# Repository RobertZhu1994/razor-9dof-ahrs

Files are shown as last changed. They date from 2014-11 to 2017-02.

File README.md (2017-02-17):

Razor AHRS v1.4.2
---

This is a "fab-able" version of the <a href="https://www.sparkfun.com/products/retired/10736">Sparkfun 9DOF IMU board</a>, modified so that it can be made with a desktop CNC router.

Full documentation on <a href="https://www.instructables.com/id/9-Degrees-of-Freedom-IMU/">Instructables</a>.

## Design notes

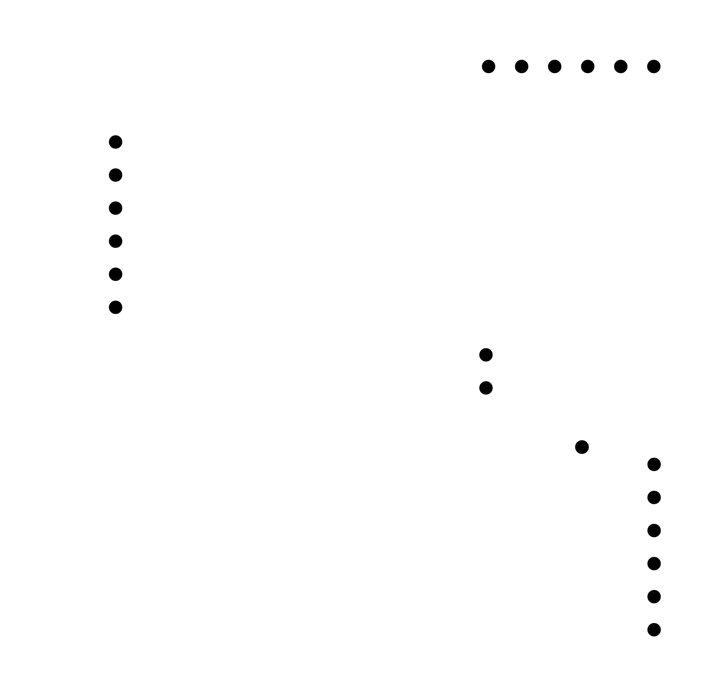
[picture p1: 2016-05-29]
PCB/9DofEagle-Holes.png

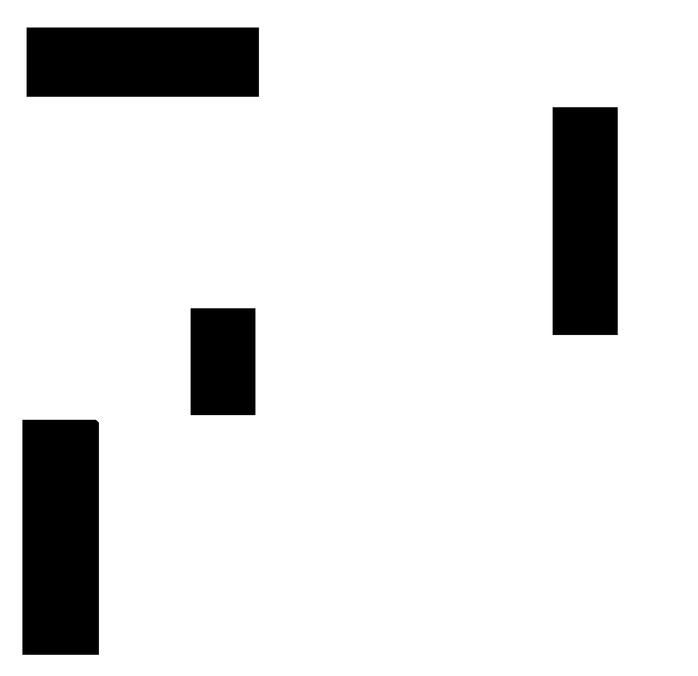
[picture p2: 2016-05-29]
PCB/9DofEagle-Back.png

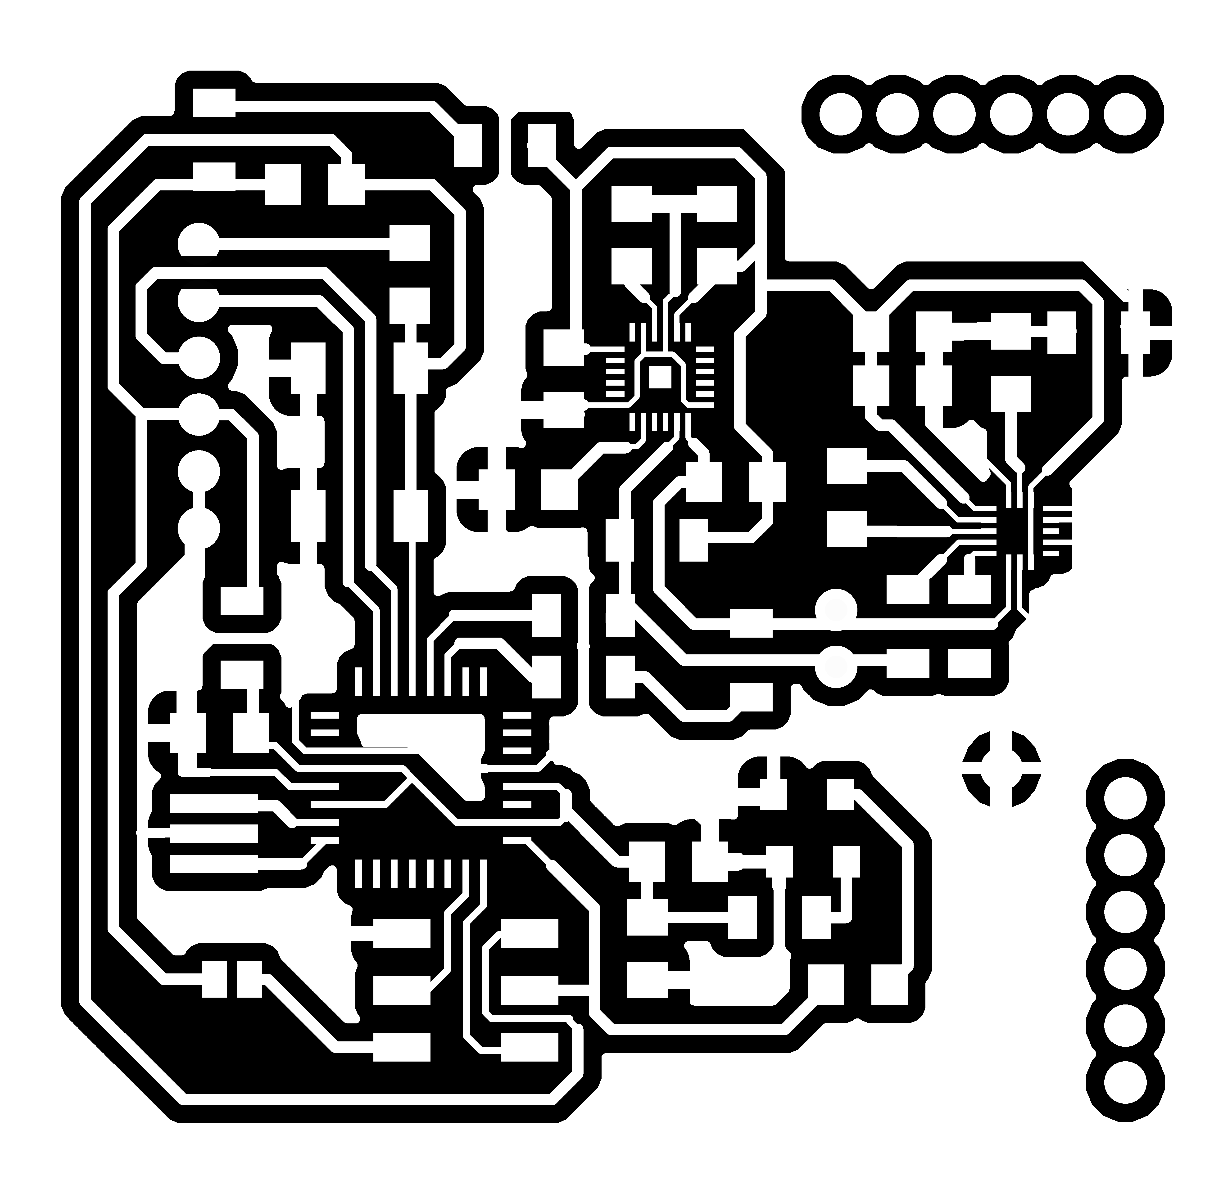
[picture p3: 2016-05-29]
PCB/9DofEagle-Traces.png

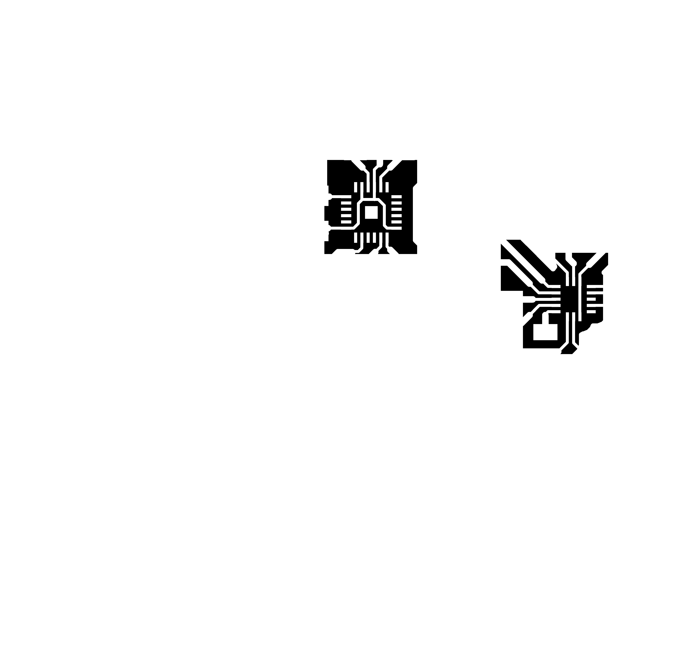
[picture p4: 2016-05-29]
PCB/9DofEagle-Detail.png

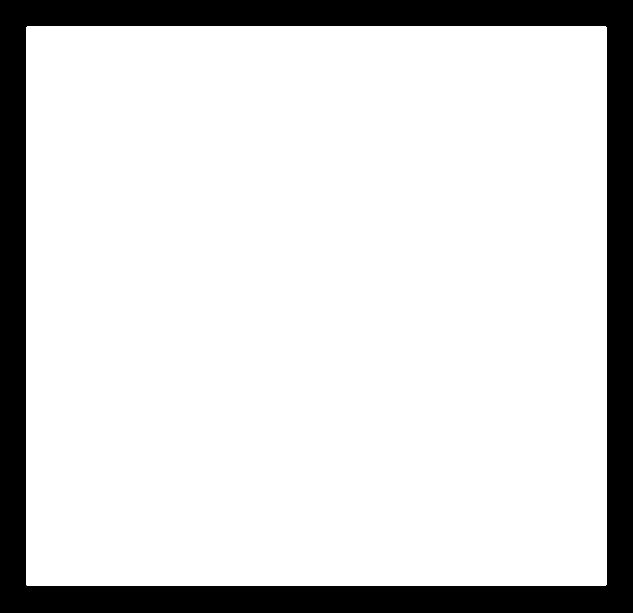
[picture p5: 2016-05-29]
PCB/9DofEagle-Outline.png

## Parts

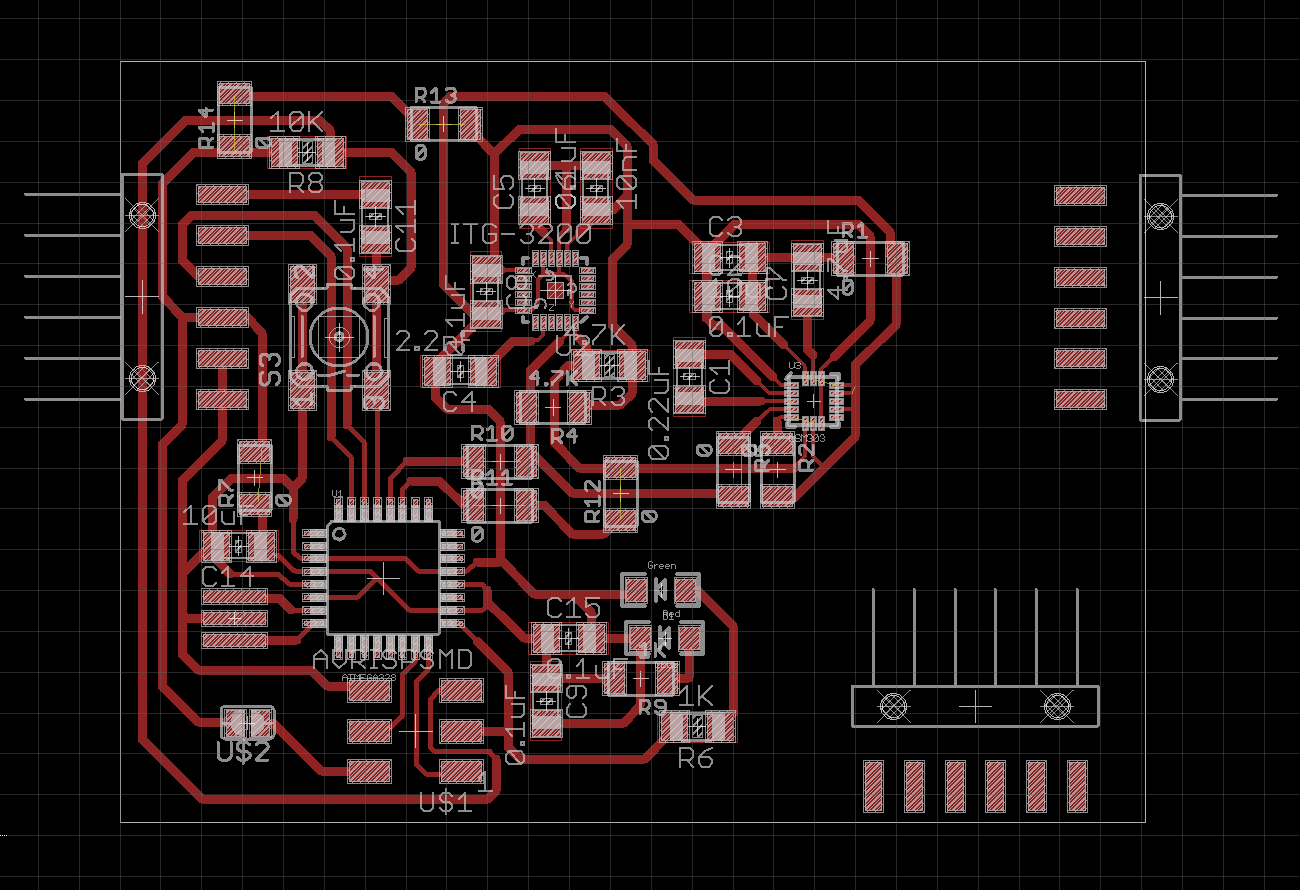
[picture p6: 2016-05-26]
PCB/Components.png

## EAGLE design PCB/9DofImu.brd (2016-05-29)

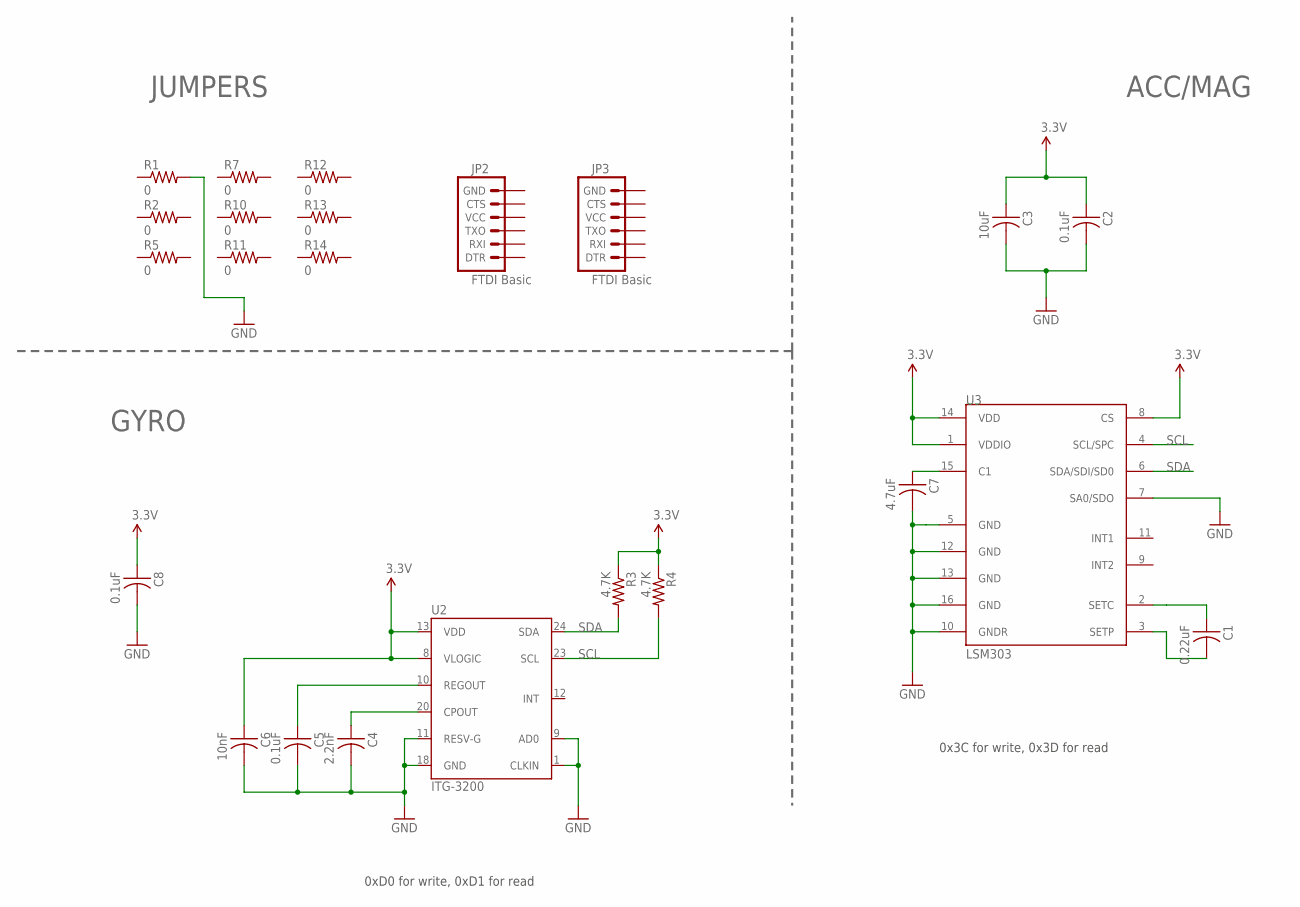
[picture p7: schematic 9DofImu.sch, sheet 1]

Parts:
C1: 0.22uF; C1206
C2, C5, C8: 0.1uF; C1206
C3: 10uF; C1206
C4: 2.2nF; C1206
C6: 10nF; C1206
C7: 4.7uF; C1206
JP2, JP3: FTDI Basic; 1X06-KIT
R1, R2, R5, R7, R10, R11, R12, R13, R14: 0; R1206FAB
R3: 4.7K; R1206
R4: 4.7K; R1206FAB
U2: ITG-3200; QFN-24
U3: LSM303; LGA16-3MM

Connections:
3.3V: C2.1, C3.1, C6.1, C8.1, R3.1, R4.1, U2.8 (VLOGIC), U2.13 (VDD), U3.1 (VDDIO), U3.8 (CS), U3.14 (VDD); also elsewhere on the board
GND: C2.2, C3.2, C4.2, C5.2, C6.2, C7.2, C8.2, R1.2, U2.1 (CLKIN), U2.9 (AD0), U2.11 (RESV-G), U2.18 (GND), U3.5 (GND), U3.7 (SA0/SDO), U3.10 (GNDR), U3.12 (GND), U3.13 (GND), U3.16 (GND); also elsewhere on the board
unnamed: C4.1, U2.20 (CPOUT)
unnamed: C5.1, U2.10 (REGOUT)
unnamed: C7.1, U3.15 (C1)
unnamed: C1.1, U3.2 (SETC)
unnamed: C1.2, U3.3 (SETP)
SCL: R4.2, U2.23 (SCL), U3.4 (SCL/SPC); also elsewhere on the board
SDA: R3.2, U2.24 (SDA), U3.6 (SDA/SDI/SD0); also elsewhere on the board

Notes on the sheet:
0xD0 for write, 0xD1 for read
0x3C for write, 0x3D for read
JUMPERS
ACC/MAG
GYRO

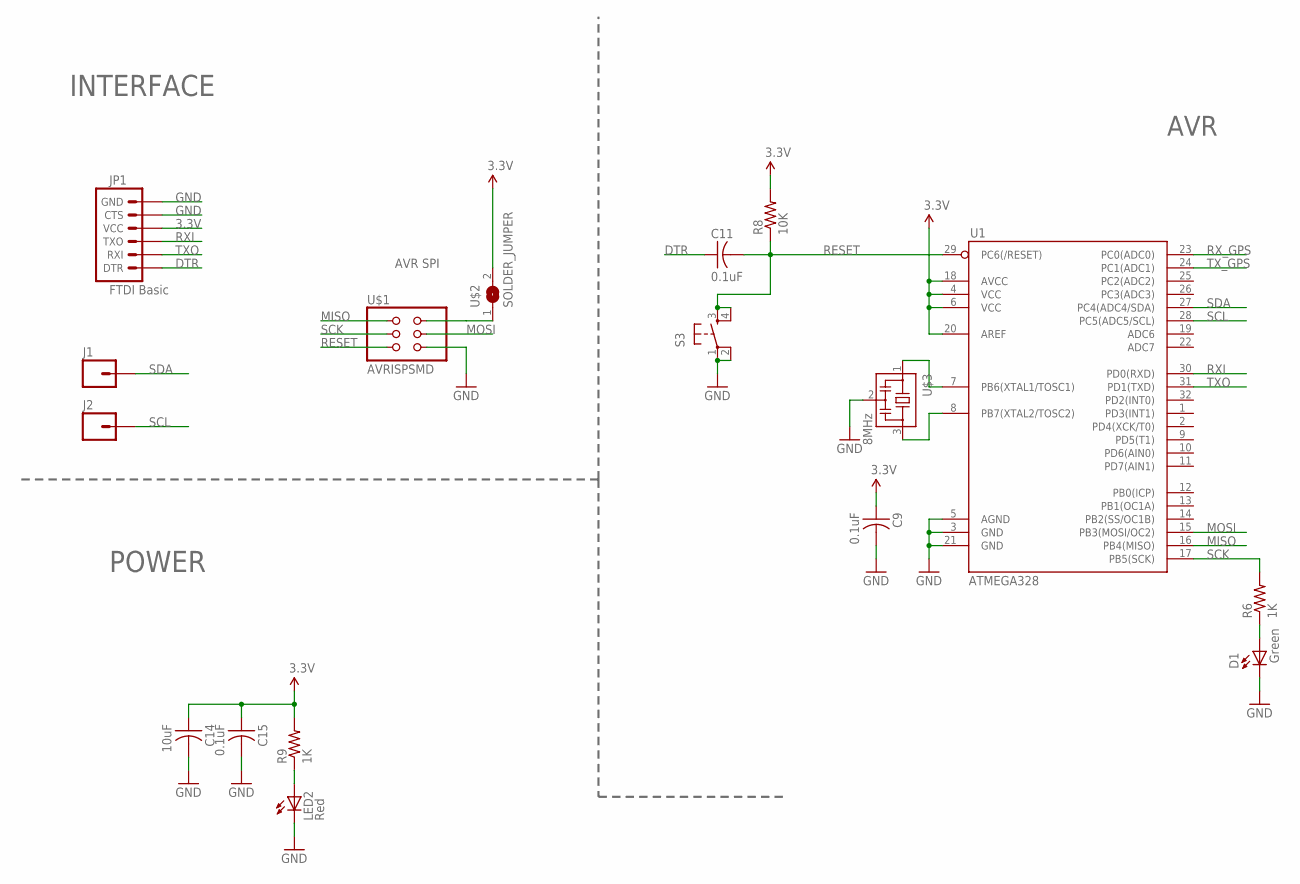
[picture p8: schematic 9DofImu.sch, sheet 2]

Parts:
C9, C11, C15: 0.1uF; C1206
C14: 10uF; C1206
D1: Green; LED-1206
J1, J2: M01PTH; 1X01
JP1: FTDI Basic; 1X06-KIT
LED2: Red; LED-1206
R6: 1K; R1206
R8: 10K; R1206
R9: 1K; R1206FAB
S3: 6MM_SWITCH6MM_SWITCH; 6MM_SWITCH
U1: ATMEGA328; TQFP32-08
U$1: AVRISPSMD; 2X03SMD
U$2: SOLDER_JUMPER; SJFAB
U$3: 8MHz; EFOBM

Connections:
3.3V: C9.1, C14.1, C15.1, JP1.4 (VCC), R8.2, R9.2, U1.4 (VCC), U1.6 (VCC), U1.18 (AVCC), U1.20 (AREF), U$2.2; also elsewhere on the board
DTR: C11.1, JP1.1 (DTR)
GND: C9.2, C14.2, C15.2, D1.C, JP1.5 (CTS), JP1.6 (GND), LED2.C, S3.1, S3.2 (P1), U1.3 (GND), U1.5 (AGND), U1.21 (GND), U$1.6 (GND), U$3.2; also elsewhere on the board
MISO: U1.16 (PB4(MISO)), U$1.1 (MISO)
MOSI: U1.15 (PB3(MOSI/OC2)), U$1.4 (MOSI)
unnamed: LED2.A, R9.1
unnamed: U$1.2 (VCC), U$2.1
unnamed: D1.A, R6.1
unnamed: U1.8 (PB7(XTAL2/TOSC2)), U$3.3
unnamed: U1.7 (PB6(XTAL1/TOSC1)), U$3.1
RESET: C11.2, R8.1, S3.3 (S), S3.4 (S1), U1.29 (PC6(/RESET)), U$1.5 (RST)
RXI: JP1.3 (TXO), U1.30 (PD0(RXD))
RX_GPS: U1.23 (PC0(ADC0))
SCK: R6.2, U1.17 (PB5(SCK)), U$1.3 (SCK)
SCL: J2.1, U1.28 (PC5(ADC5/SCL)); also elsewhere on the board
SDA: J1.1, U1.27 (PC4(ADC4/SDA)); also elsewhere on the board
TXO: JP1.2 (RXI), U1.31 (PD1(TXD))
TX_GPS: U1.24 (PC1(ADC1))

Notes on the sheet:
AVR
INTERFACE
POWER
AVR SPI

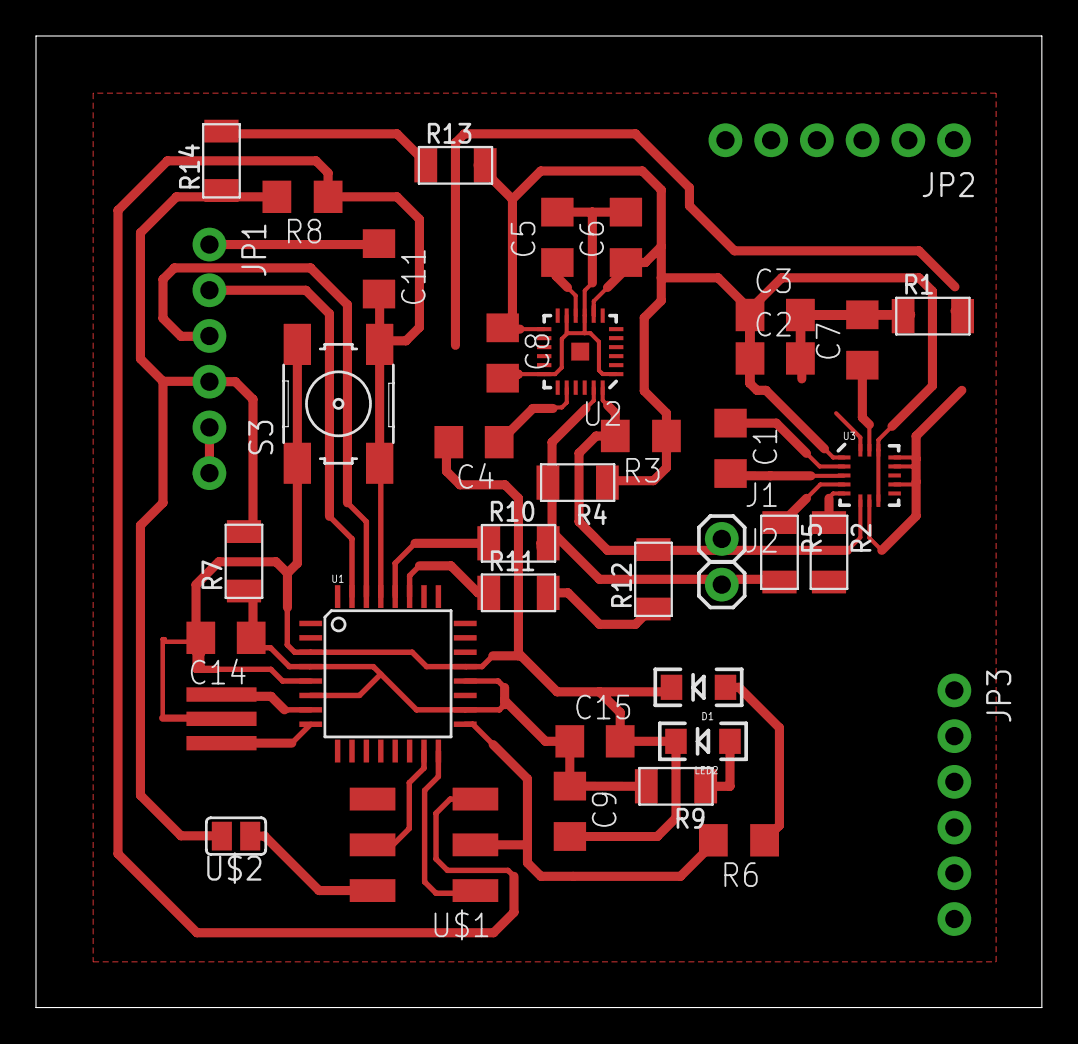
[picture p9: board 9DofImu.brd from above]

Board: 2 copper layers, 55.9 x 54.0 mm, 40 parts (0 on the bottom side), 21 nets.

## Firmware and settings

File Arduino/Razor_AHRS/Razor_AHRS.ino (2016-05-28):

/***************************************************************************************************************
* Razor AHRS Firmware v1.4.2 mod
* 9 Degree of Measurement Attitude and Heading Reference System
* for Sparkfun "9DOF Razor IMU" (SEN-10125 and SEN-10736)
* and "9DOF Sensor Stick" (SEN-10183, 10321 and SEN-10724)
*
* Released under GNU GPL (General Public License) v3.0
* Copyright (C) 2013 Peter Bartz [http://ptrbrtz.net]
* Copyright (C) 2011-2012 Quality & Usability Lab, Deutsche Telekom Laboratories, TU Berlin
*
* Infos, updates, bug reports, contributions and feedback:
*     https://github.com/ptrbrtz/razor-9dof-ahrs
*
*
* History:
*   * Original code (http://code.google.com/p/sf9domahrs/) by Doug Weibel and Jose Julio,
*     based on ArduIMU v1.5 by Jordi Munoz and William Premerlani, Jose Julio and Doug Weibel. Thank you!
*
*   * Updated code (http://groups.google.com/group/sf_9dof_ahrs_update) by David Malik (david.zsolt.malik@gmail.com)
*     for new Sparkfun 9DOF Razor hardware (SEN-10125).
*
*   * Updated and extended by Peter Bartz (peter-bartz@gmx.de):
*     * v1.3.0
*       * Cleaned up, streamlined and restructured most of the code to make it more comprehensible.
*       * Added sensor calibration (improves precision and responsiveness a lot!).
*       * Added binary yaw/pitch/roll output.#oc
*       * Added basic serial command interface to set output modes/calibrate sensors/synch stream/etc.
*       * Added support to synch automatically when using Rovering Networks Bluetooth modules (and compatible).
*       * Wrote new easier to use test program (using Processing).
*       * Added support for new version of "9DOF Razor IMU": SEN-10736.
*       --> The output of this code is not compatible with the older versions!
*       --> A Processing sketch to test the tracker is available.
*     * v1.3.1
*       * Initializing rotation matrix based on start-up sensor readings -> orientation OK right away.
*       * Adjusted gyro low-pass filter and output rate settings.
*     * v1.3.2
*       * Adapted code to work with new Arduino 1.0 (and older versions still).
*     * v1.3.3
*       * Improved synching.
*     * v1.4.0
*       * Added support for SparkFun "9DOF Sensor Stick" (versions SEN-10183, SEN-10321 and SEN-10724).
*     * v1.4.1
*       * Added output modes to read raw and/or calibrated sensor data in text or binary format.
*       * Added static magnetometer soft iron distortion compensation
*     * v1.4.2
*       * (No core firmware changes)
*
* TODOs:
*   * Allow optional use of EEPROM for storing and reading calibration values.
*   * Use self-test and temperature-compensation features of the sensors.
***************************************************************************************************************/

/*
  "9DOF Razor IMU" hardware versions: SEN-10125 and SEN-10736

  ATMega328@3.3V, 8MHz

  ADXL345  : Accelerometer
  HMC5843  : Magnetometer on SEN-10125
  HMC5883L : Magnetometer on SEN-10736
  ITG-3200 : Gyro

  Arduino IDE : Select board "Arduino Pro or Pro Mini (3.3v, 8Mhz) w/ATmega328"
*/

/*
  "9DOF Sensor Stick" hardware versions: SEN-10183, SEN-10321 and SEN-10724

  ADXL345  : Accelerometer
  HMC5843  : Magnetometer on SEN-10183 and SEN-10321
  HMC5883L : Magnetometer on SEN-10724
  ITG-3200 : Gyro
*/

/*
  Axis definition (differs from definition printed on the board!):
    X axis pointing forward (towards the short edge with the connector holes)
    Y axis pointing to the right
    and Z axis pointing down.
    
  Positive yaw   : clockwise
  Positive roll  : right wing down
  Positive pitch : nose up
  
  Transformation order: first yaw then pitch then roll.
*/

/*
  Serial commands that the firmware understands:
  
  "#o<params>" - Set OUTPUT mode and parameters. The available options are:
  
      // Streaming output
      "#o0" - DISABLE continuous streaming output. Also see #f below.
      "#o1" - ENABLE continuous streaming output.
      
      // Angles output
      "#ob" - Output angles in BINARY format (yaw/pitch/roll as binary float, so one output frame
              is 3x4 = 12 bytes long).
      "#ot" - Output angles in TEXT format (Output frames have form like "#YPR=-142.28,-5.38,33.52",
              followed by carriage return and line feed [\r\n]).
      
      // Sensor calibration
      "#oc" - Go to CALIBRATION output mode.
      "#on" - When in calibration mode, go on to calibrate NEXT sensor.
      
      // Sensor data output
      "#osct" - Output CALIBRATED SENSOR data of all 9 axes in TEXT format.
                One frame consist of three lines - one for each sensor: acc, mag, gyr.
      "#osrt" - Output RAW SENSOR data of all 9 axes in TEXT format.
                One frame consist of three lines - one for each sensor: acc, mag, gyr.
      "#osbt" - Output BOTH raw and calibrated SENSOR data of all 9 axes in TEXT format.
                One frame consist of six lines - like #osrt and #osct combined (first RAW, then CALIBRATED).
                NOTE: This is a lot of number-to-text conversion work for the little 8MHz chip on the Razor boards.
                In fact it's too much and an output frame rate of 50Hz can not be maintained. #osbb.
      "#oscb" - Output CALIBRATED SENSOR data of all 9 axes in BINARY format.
                One frame consist of three 3x3 float values = 36 bytes. Order is: acc x/y/z, mag x/y/z, gyr x/y/z.
      "#osrb" - Output RAW SENSOR data of all 9 axes in BINARY format.
                One frame consist of three 3x3 float values = 36 bytes. Order is: acc x/y/z, mag x/y/z, gyr x/y/z.
      "#osbb" - Output BOTH raw and calibrated SENSOR data of all 9 axes in BINARY format.
                One frame consist of 2x36 = 72 bytes - like #osrb and #oscb combined (first RAW, then CALIBRATED).
      
      // Error message output        
      "#oe0" - Disable ERROR message output.
      "#oe1" - Enable ERROR message output.
    
    
  "#f" - Request one output frame - useful when continuous output is disabled and updates are
         required in larger intervals only. Though #f only requests one reply, replies are still
         bound to the internal 20ms (50Hz) time raster. So worst case delay that #f can add is 19.99ms.
         
         
  "#s<xy>" - Request synch token - useful to find out where the frame boundaries are in a continuous
         binary stream or to see if tracker is present and answering. The tracker will send
         "#SYNCH<xy>\r\n" in response (so it's possible to read using a readLine() function).
         x and y are two mandatory but arbitrary bytes that can be used to find out which request
         the answer belongs to.
          
          
  ("#C" and "#D" - Reserved for communication with optional Bluetooth module.)
  
  Newline characters are not required. So you could send "#ob#o1#s", which
  would set binary output mode, enable continuous streaming output and request
  a synch token all at once.
  
  The status LED will be on if streaming output is enabled and off otherwise.
  
  Byte order of binary output is little-endian: least significant byte comes first.
*/



/*****************************************************************/
/*********** USER SETUP AREA! Set your options here! *************/
/*****************************************************************/

// HARDWARE OPTIONS
/*****************************************************************/
// Select your hardware here by uncommenting one line!
#define HW__VERSION_CODE 10125 // SparkFun "9DOF Razor IMU" version "SEN-10125" (HMC5843 magnetometer)
//#define HW__VERSION_CODE 10736 // SparkFun "9DOF Razor IMU" version "SEN-10736" (HMC5883L magnetometer)
//#define HW__VERSION_CODE 10183 // SparkFun "9DOF Sensor Stick" version "SEN-10183" (HMC5843 magnetometer)
//#define HW__VERSION_CODE 10321 // SparkFun "9DOF Sensor Stick" version "SEN-10321" (HMC5843 magnetometer)
//#define HW__VERSION_CODE 10724 // SparkFun "9DOF Sensor Stick" version "SEN-10724" (HMC5883L magnetometer)


// OUTPUT OPTIONS
/*****************************************************************/
// Set your serial port baud rate used to send out data here!
#define OUTPUT__BAUD_RATE 57600

// Sensor data output interval in milliseconds
// This may not work, if faster than 20ms (=50Hz)
// Code is tuned for 20ms, so better leave it like that
#define OUTPUT__DATA_INTERVAL 20  // in milliseconds

// Output mode definitions (do not change)
#define OUTPUT__MODE_CALIBRATE_SENSORS 0 // Outputs sensor min/max values as text for manual calibration
#define OUTPUT__MODE_ANGLES 1 // Outputs yaw/pitch/roll in degrees
#define OUTPUT__MODE_SENSORS_CALIB 2 // Outputs calibrated sensor values for all 9 axes
#define OUTPUT__MODE_SENSORS_RAW 3 // Outputs raw (uncalibrated) sensor values for all 9 axes
#define OUTPUT__MODE_SENSORS_BOTH 4 // Outputs calibrated AND raw sensor values for all 9 axes
// Output format definitions (do not change)
#define OUTPUT__FORMAT_TEXT 0 // Outputs data as text
#define OUTPUT__FORMAT_BINARY 1 // Outputs data as binary float

// Select your startup output mode and format here!
int output_mode = OUTPUT__MODE_ANGLES;
int output_format = OUTPUT__FORMAT_TEXT;

// Select if serial continuous streaming output is enabled per default on startup.
#define OUTPUT__STARTUP_STREAM_ON true  // true or false

// If set true, an error message will be output if we fail to read sensor data.
// Message format: "!ERR: reading <sensor>", followed by "\r\n".
boolean output_errors = false;  // true or false

// Bluetooth
// You can set this to true, if you have a Rovering Networks Bluetooth Module attached.
// The connect/disconnect message prefix of the module has to be set to "#".
// (Refer to manual, it can be set like this: SO,#)
// When using this, streaming output will only be enabled as long as we're connected. That way
// receiver and sender are synchronzed easily just by connecting/disconnecting.
// It is not necessary to set this! It just makes life easier when writing code for
// the receiving side. The Processing test sketch also works without setting this.
// NOTE: When using this, OUTPUT__STARTUP_STREAM_ON has no effect!
#define OUTPUT__HAS_RN_BLUETOOTH false  // true or false


// SENSOR CALIBRATION
/*****************************************************************/
// How to calibrate? Read the tutorial at http://dev.qu.tu-berlin.de/projects/sf-razor-9dof-ahrs
// Put MIN/MAX and OFFSET readings for your board here!
// Accelerometer
// "accel x,y,z (min/max) = X_MIN/X_MAX  Y_MIN/Y_MAX  Z_MIN/Z_MAX"
#define ACCEL_X_MIN ((float) -292)
#define ACCEL_X_MAX ((float) 267)
#define ACCEL_Y_MIN ((float) -280)
#define ACCEL_Y_MAX ((float) 267)
#define ACCEL_Z_MIN ((float) -289)
#define ACCEL_Z_MAX ((float) 262)

// Magnetometer (standard calibration mode)
// "magn x,y,z (min/max) = X_MIN/X_MAX  Y_MIN/Y_MAX  Z_MIN/Z_MAX"
#define MAGN_X_MIN ((float) -632)
#define MAGN_X_MAX ((float) 761)
#define MAGN_Y_MIN ((float) -621)
#define MAGN_Y_MAX ((float) 698)
#define MAGN_Z_MIN ((float) -780)
#define MAGN_Z_MAX ((float) 703)

// Magnetometer (extended calibration mode)
// Uncommend to use extended magnetometer calibration (compensates hard & soft iron errors)
//#define CALIBRATION__MAGN_USE_EXTENDED true
//const float magn_ellipsoid_center[3] = {0, 0, 0};
//const float magn_ellipsoid_transform[3][3] = {{0, 0, 0}, {0, 0, 0}, {0, 0, 0}};

// Gyroscope
// "gyro x,y,z (current/average) = .../OFFSET_X  .../OFFSET_Y  .../OFFSET_Z
#define GYRO_AVERAGE_OFFSET_X ((float) -24.75)
#define GYRO_AVERAGE_OFFSET_Y ((float) 75.10)
#define GYRO_AVERAGE_OFFSET_Z ((float) -7.98)

/*
// Calibration example:

// "accel x,y,z (min/max) = -277.00/264.00  -256.00/278.00  -299.00/235.00"
#define ACCEL_X_MIN ((float) -277)
#define ACCEL_X_MAX ((float) 264)
#define ACCEL_Y_MIN ((float) -256)
#define ACCEL_Y_MAX ((float) 278)
#define ACCEL_Z_MIN ((float) -299)
#define ACCEL_Z_MAX ((float) 235)

// "magn x,y,z (min/max) = -511.00/581.00  -516.00/568.00  -489.00/486.00"
//#define MAGN_X_MIN ((float) -511)
//#define MAGN_X_MAX ((float) 581)
//#define MAGN_Y_MIN ((float) -516)
//#define MAGN_Y_MAX ((float) 568)
//#define MAGN_Z_MIN ((float) -489)
//#define MAGN_Z_MAX ((float) 486)

// Extended magn
#define CALIBRATION__MAGN_USE_EXTENDED true
const float magn_ellipsoid_center[3] = {91.5, -13.5, -48.1};
const float magn_ellipsoid_transform[3][3] = {{0.902, -0.00354, 0.000636}, {-0.00354, 0.9, -0.00599}, {0.000636, -0.00599, 1}};

// Extended magn (with Sennheiser HD 485 headphones)
//#define CALIBRATION__MAGN_USE_EXTENDED true
//const float magn_ellipsoid_center[3] = {72.3360, 23.0954, 53.6261};
//const float magn_ellipsoid_transform[3][3] = {{0.879685, 0.000540833, -0.0106054}, {0.000540833, 0.891086, -0.0130338}, {-0.0106054, -0.0130338, 0.997494}};

//"gyro x,y,z (current/average) = -40.00/-42.05  98.00/96.20  -18.00/-18.36"
#define GYRO_AVERAGE_OFFSET_X ((float) -42.05)
#define GYRO_AVERAGE_OFFSET_Y ((float) 96.20)
#define GYRO_AVERAGE_OFFSET_Z ((float) -18.36)
*/


// DEBUG OPTIONS
/*****************************************************************/
// When set to true, gyro drift correction will not be applied
#define DEBUG__NO_DRIFT_CORRECTION false
// Print elapsed time after each I/O loop
#define DEBUG__PRINT_LOOP_TIME false


/*****************************************************************/
/****************** END OF USER SETUP AREA!  *********************/
/*****************************************************************/










// Check if hardware version code is defined
#ifndef HW__VERSION_CODE
  // Generate compile error
  #error YOU HAVE TO SELECT THE HARDWARE YOU ARE USING! See "HARDWARE OPTIONS" in "USER SETUP AREA" at top of Razor_AHRS.ino!
#endif

#include <Wire.h>

// Sensor calibration scale and offset values
#define ACCEL_X_OFFSET ((ACCEL_X_MIN + ACCEL_X_MAX) / 2.0f)
#define ACCEL_Y_OFFSET ((ACCEL_Y_MIN + ACCEL_Y_MAX) / 2.0f)
#define ACCEL_Z_OFFSET ((ACCEL_Z_MIN + ACCEL_Z_MAX) / 2.0f)
#define ACCEL_X_SCALE (GRAVITY / (ACCEL_X_MAX - ACCEL_X_OFFSET))
#define ACCEL_Y_SCALE (GRAVITY / (ACCEL_Y_MAX - ACCEL_Y_OFFSET))
#define ACCEL_Z_SCALE (GRAVITY / (ACCEL_Z_MAX - ACCEL_Z_OFFSET))

#define MAGN_X_OFFSET ((MAGN_X_MIN + MAGN_X_MAX) / 2.0f)
#define MAGN_Y_OFFSET ((MAGN_Y_MIN + MAGN_Y_MAX) / 2.0f)
#define MAGN_Z_OFFSET ((MAGN_Z_MIN + MAGN_Z_MAX) / 2.0f)
#define MAGN_X_SCALE (100.0f / (MAGN_X_MAX - MAGN_X_OFFSET))
#define MAGN_Y_SCALE (100.0f / (MAGN_Y_MAX - MAGN_Y_OFFSET))
#define MAGN_Z_SCALE (100.0f / (MAGN_Z_MAX - MAGN_Z_OFFSET))


// Gain for gyroscope (ITG-3200)
#define GYRO_GAIN 0.06957 // Same gain on all axes
#define GYRO_SCALED_RAD(x) (x * TO_RAD(GYRO_GAIN)) // Calculate the scaled gyro readings in radians per second

// DCM parameters
#define Kp_ROLLPITCH 0.02f
#define Ki_ROLLPITCH 0.00002f
#define Kp_YAW 1.2f
#define Ki_YAW 0.00002f

// Stuff
#define STATUS_LED_PIN 13  // Pin number of status LED
#define GRAVITY 256.0f // "1G reference" used for DCM filter and accelerometer calibration
#define TO_RAD(x) (x * 0.01745329252)  // *pi/180
#define TO_DEG(x) (x * 57.2957795131)  // *180/pi

// Sensor variables
float accel[3];  // Actually stores the NEGATED acceleration (equals gravity, if board not moving).
float accel_min[3];
float accel_max[3];

float magnetom[3];
float magnetom_min[3];
float magnetom_max[3];
float magnetom_tmp[3];

float gyro[3];
float gyro_average[3];
int gyro_num_samples = 0;

// DCM variables
float MAG_Heading;
float Accel_Vector[3]= {0, 0, 0}; // Store the acceleration in a vector
float Gyro_Vector[3]= {0, 0, 0}; // Store the gyros turn rate in a vector
float Omega_Vector[3]= {0, 0, 0}; // Corrected Gyro_Vector data
float Omega_P[3]= {0, 0, 0}; // Omega Proportional correction
float Omega_I[3]= {0, 0, 0}; // Omega Integrator
float Omega[3]= {0, 0, 0};
float errorRollPitch[3] = {0, 0, 0};
float errorYaw[3] = {0, 0, 0};
float DCM_Matrix[3][3] = {{1, 0, 0}, {0, 1, 0}, {0, 0, 1}};
float Update_Matrix[3][3] = {{0, 1, 2}, {3, 4, 5}, {6, 7, 8}};
float Temporary_Matrix[3][3] = {{0, 0, 0}, {0, 0, 0}, {0, 0, 0}};

// Euler angles
float yaw;
float pitch;
float roll;

// DCM timing in the main loop
unsigned long timestamp;
unsigned long timestamp_old;
float G_Dt; // Integration time for DCM algorithm

// More output-state variables
boolean output_stream_on;
boolean output_single_on;
int curr_calibration_sensor = 0;
boolean reset_calibration_session_flag = true;
int num_accel_errors = 0;
int num_magn_errors = 0;
int num_gyro_errors = 0;

void read_sensors() {
  Read_Gyro(); // Read gyroscope
  Read_Accel(); // Read accelerometer
  Read_Magn(); // Read magnetometer
}
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
void loop()
{
  // Read incoming control messages
  if (Serial.available() >= 2)
  {
    if (Serial.read() == '#') // Start of new control message
    {
      int command = Serial.read(); // Commands
      if (command == 'f') // request one output _f_rame
        output_single_on = true;
      else if (command == 's') // _s_ynch request
      {
        // Read ID
        byte id[2];
        id[0] = readChar();
        id[1] = readChar();
        
        // Reply with synch message
        Serial.print("#SYNCH");
        Serial.write(id, 2);
        Serial.println();
      }
      else if (command == 'o') // Set _o_utput mode
      {
        char output_param = readChar();
        if (output_param == 'n')  // Calibrate _n_ext sensor
        {
          curr_calibration_sensor = (curr_calibration_sensor + 1) % 3;
          reset_calibration_session_flag = true;
        }
        else if (output_param == 't') // Output angles as _t_ext
        {
          output_mode = OUTPUT__MODE_ANGLES;
          output_format = OUTPUT__FORMAT_TEXT;
        }
        else if (output_param == 'b') // Output angles in _b_inary format
        {
          output_mode = OUTPUT__MODE_ANGLES;
          output_format = OUTPUT__FORMAT_BINARY;
        }
        else if (output_param == 'c') // Go to _c_alibration mode
        {
          output_mode = OUTPUT__MODE_CALIBRATE_SENSORS;
          reset_calibration_session_flag = true;
        }
        else if (output_param == 's') // Output _s_ensor values
        {
          char values_param = readChar();
          char format_param = readChar();
          if (values_param == 'r')  // Output _r_aw sensor values
            output_mode = OUTPUT__MODE_SENSORS_RAW;
          else if (values_param == 'c')  // Output _c_alibrated sensor values
            output_mode = OUTPUT__MODE_SENSORS_CALIB;
          else if (values_param == 'b')  // Output _b_oth sensor values (raw and calibrated)
            output_mode = OUTPUT__MODE_SENSORS_BOTH;

          if (format_param == 't') // Output values as _t_text
            output_format = OUTPUT__FORMAT_TEXT;
          else if (format_param == 'b') // Output values in _b_inary format
            output_format = OUTPUT__FORMAT_BINARY;
        }
        else if (output_param == '0') // Disable continuous streaming output
        {
          turn_output_stream_off();
          reset_calibration_session_flag = true;
        }
        else if (output_param == '1') // Enable continuous streaming output
        {
          reset_calibration_session_flag = true;
          turn_output_stream_on();
        }
        else if (output_param == 'e') // _e_rror output settings
        {
          char error_param = readChar();
          if (error_param == '0') output_errors = false;
          else if (error_param == '1') output_errors = true;
          else if (error_param == 'c') // get error count
          {
            Serial.print("#AMG-ERR:");
            Serial.print(num_accel_errors); Serial.print(",");
            Serial.print(num_magn_errors); Serial.print(",");
            Serial.println(num_gyro_errors);
          }
        }
      }
#if OUTPUT__HAS_RN_BLUETOOTH == true
      // Read messages from bluetooth module
      // For this to work, the connect/disconnect message prefix of the module has to be set to "#".
      else if (command == 'C') // Bluetooth "#CONNECT" message (does the same as "#o1")
        turn_output_stream_on();
      else if (command == 'D') // Bluetooth "#DISCONNECT" message (does the same as "#o0")
        turn_output_stream_off();
#endif // OUTPUT__HAS_RN_BLUETOOTH == true
    }
    else
    { } // Skip character
  }

  // Time to read the sensors again?
  if((millis() - timestamp) >= OUTPUT__DATA_INTERVAL)
  {
    timestamp_old = timestamp;
    timestamp = millis();
    if (timestamp > timestamp_old)
      G_Dt = (float) (timestamp - timestamp_old) / 1000.0f; // Real time of loop run. We use this on the DCM algorithm (gyro integration time)
    else G_Dt = 0;

    // Update sensor readings
    read_sensors();

    if (output_mode == OUTPUT__MODE_CALIBRATE_SENSORS)  // We're in calibration mode
    {
      check_reset_calibration_session();  // Check if this session needs a reset
      if (output_stream_on || output_single_on) output_calibration(curr_calibration_sensor);
    }
    else if (output_mode == OUTPUT__MODE_ANGLES)  // Output angles
    {
      // Apply sensor calibration
      compensate_sensor_errors();
    
      // Run DCM algorithm
      Compass_Heading(); // Calculate magnetic heading
      Matrix_update();
      Normalize();
      Drift_correction();
      Euler_angles();
      
      if (output_stream_on || output_single_on) output_angles();
    }
    else  // Output sensor values
    {      
      if (output_stream_on || output_single_on) output_sensors();
    }
    
    output_single_on = false;
    
#if DEBUG__PRINT_LOOP_TIME == true
    Serial.print("loop time (ms) = ");
    Serial.println(millis() - timestamp);
#endif
  }
#if DEBUG__PRINT_LOOP_TIME == true
  else
  {
    Serial.println("waiting...");
  }
#endif
}

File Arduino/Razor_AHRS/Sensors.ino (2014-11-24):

/* This file is part of the Razor AHRS Firmware */

// I2C code to read the sensors

// Sensor I2C addresses
#define GYRO_ADDRESS ((int) 0x68) // 0x68 = 0xD0 / 2
#define ACC_MAG_ADDRESS  ((int) 0x1E) // 0x1E = 0x3C / 2

// Arduino backward compatibility macros
#if ARDUINO >= 100
  #define WIRE_SEND(b) Wire.write((byte) b) 
  #define WIRE_RECEIVE() Wire.read() 
#else
  #define WIRE_SEND(b) Wire.send(b)
  #define WIRE_RECEIVE() Wire.receive() 
#endif


void I2C_Init()
{
  Wire.begin();
}

void Acc_Mag_Init()
{

  //set acceleration data rate to 50Hz, enable all acc axes
  Wire.beginTransmission(ACC_MAG_ADDRESS);
  WIRE_SEND(0x20);//CTRL1 register
  WIRE_SEND(0x57);//01010111
  Wire.endTransmission();
  delay(5); 
  
  //set acceleration scale +/-16G
  Wire.beginTransmission(ACC_MAG_ADDRESS);
  WIRE_SEND(0x21);//CTRL2 register
  WIRE_SEND(0x20);//0010000
  Wire.endTransmission();
  delay(5); 
  
  //set magnetic resolution to high and data rate to 50Hz
  Wire.beginTransmission(ACC_MAG_ADDRESS);
  WIRE_SEND(0x24);//CTRL5 register
  WIRE_SEND(0x70);//01110000
  Wire.endTransmission();
  delay(5); 
  
  //set magnetic scale to +/-8 Gauss
  Wire.beginTransmission(ACC_MAG_ADDRESS);
  WIRE_SEND(0x25);//CTRL6 register
  WIRE_SEND(0x40);//01000000
  Wire.endTransmission();
  delay(5); 
  
  //set magnetometer to continuous mode
  Wire.beginTransmission(ACC_MAG_ADDRESS);
  WIRE_SEND(0x26);//CTRL7 register
  WIRE_SEND(0x00);//
  Wire.endTransmission();
  delay(5); 
 
}

void Read_Magn()
{
  int i = 0;
  byte buff[6];
  
  Wire.beginTransmission(ACC_MAG_ADDRESS); 
  WIRE_SEND(0x08 | 0x80);  // Sends address to read from
  Wire.endTransmission();
  
  Wire.beginTransmission(ACC_MAG_ADDRESS);
  Wire.requestFrom(ACC_MAG_ADDRESS, 6);  // Request 6 bytes
  while(Wire.available())  // ((Wire.available())&&(i<6))
  { 
    buff[i] = WIRE_RECEIVE();  // Read one byte
    i++;
  }
  Wire.endTransmission();
  
  if (i == 6)  // All bytes received?
  {
    magnetom[0] = -1 * ((((int) buff[3]) << 8) | buff[2])>>1;    // X axis
    magnetom[1] = -1 * ((((int) buff[1]) << 8) | buff[0])>>1;    // Y axis
    magnetom[2] = -1 * ((((int) buff[5]) << 8) | buff[4])>>1;    // Z axis
  }
  else
  {
    num_magn_errors++;
    if (output_errors) Serial.println("!ERR: reading acc/mag");
  }
}

void Read_Accel(){
  int i = 0;
  byte buff[6];
  
  Wire.beginTransmission(ACC_MAG_ADDRESS); 
  WIRE_SEND(0x28 | 0x80);  // Sends address to read from
  Wire.endTransmission();
  
  Wire.beginTransmission(ACC_MAG_ADDRESS);
  Wire.requestFrom(ACC_MAG_ADDRESS, 6);  // Request 6 bytes
  while(Wire.available())  // ((Wire.available())&&(i<6))
  { 
    buff[i] = WIRE_RECEIVE();  // Read one byte
    i++;
  }
  Wire.endTransmission();
  
  if (i == 6)  // All bytes received?
  {
    accel[0] = ((((int) buff[3]) << 8) | buff[2])/5;    // X axis
    accel[1] = ((((int) buff[1]) << 8) | buff[0])/5;    // Y axis
    accel[2] = ((((int) buff[5]) << 8) | buff[4])/5;    // Z axis
  }
  else
  {
    num_accel_errors++;
    if (output_errors) Serial.println("!ERR: reading acc/mag");
  }
}

void Gyro_Init()
{
  // Power up reset defaults
  Wire.beginTransmission(GYRO_ADDRESS);
  WIRE_SEND(0x3E);
  WIRE_SEND(0x80);
  Wire.endTransmission();
  delay(5);
  
  // Select full-scale range of the gyro sensors
  // Set LP filter bandwidth to 42Hz
  Wire.beginTransmission(GYRO_ADDRESS);
  WIRE_SEND(0x16);
  WIRE_SEND(0x1B);  // DLPF_CFG = 3, FS_SEL = 3
  Wire.endTransmission();
  delay(5);
  
  // Set sample rato to 50Hz
  Wire.beginTransmission(GYRO_ADDRESS);
  WIRE_SEND(0x15);
  WIRE_SEND(0x0A);  //  SMPLRT_DIV = 10 (50Hz)
  Wire.endTransmission();
  delay(5);

  // Set clock to PLL with z gyro reference
  Wire.beginTransmission(GYRO_ADDRESS);
  WIRE_SEND(0x3E);
  WIRE_SEND(0x00);
  Wire.endTransmission();
  delay(5);
}

// Reads x, y and z gyroscope registers
void Read_Gyro()
{
  int i = 0;
  byte buff[6];
  
  Wire.beginTransmission(GYRO_ADDRESS); 
  WIRE_SEND(0x1D);  // Sends address to read from
  Wire.endTransmission();
  
  Wire.beginTransmission(GYRO_ADDRESS);
  Wire.requestFrom(GYRO_ADDRESS, 6);  // Request 6 bytes
  while(Wire.available())  // ((Wire.available())&&(i<6))
  { 
    buff[i] = WIRE_RECEIVE();  // Read one byte
    i++;
  }
  Wire.endTransmission();
  
  if (i == 6)  // All bytes received?
  {
    gyro[0] = -1*((((int) buff[2]) << 8) | buff[3]);    // X axis
    gyro[1] =  -1*((((int) buff[0]) << 8) | buff[1]);   // Y axis
    gyro[2] = -1*((((int) buff[4]) << 8) | buff[5]);   //Z axis
  }
  else
  {
    num_gyro_errors++;
    if (output_errors) Serial.println("!ERR: reading gyroscope");
  }
}

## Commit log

2014-11-24 seems to be working now
    [9DofImu.brd, 9DofImu.sch]
2014-11-30 upadted pcb
    [9DofImu.brd, 9DofImu.sch]
2016-05-28 pcb updates
    [9DofImu.brd, 9DofImu.sch]
2016-05-29 i2c pin headers
    [9DofImu.brd, 9DofImu.sch]

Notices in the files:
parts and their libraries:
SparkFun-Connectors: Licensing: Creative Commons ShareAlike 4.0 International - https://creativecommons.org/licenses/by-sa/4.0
